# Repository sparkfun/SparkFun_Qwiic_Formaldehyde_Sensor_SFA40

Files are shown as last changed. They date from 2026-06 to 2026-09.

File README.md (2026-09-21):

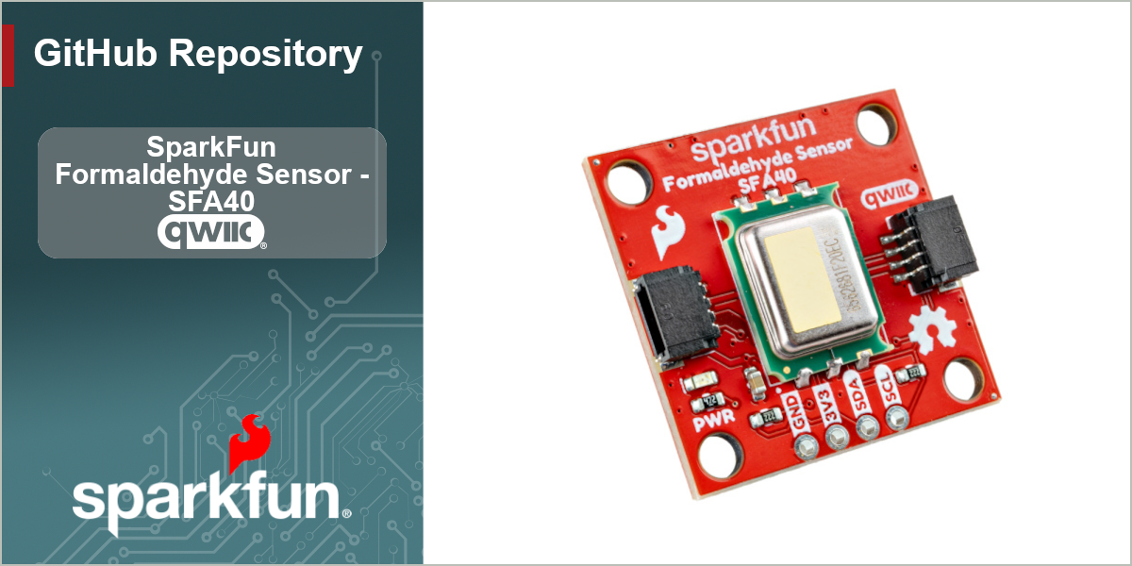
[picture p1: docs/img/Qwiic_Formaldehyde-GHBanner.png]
SparkFun Formaldehyde Sensor - SFA40 (Qwiic) (https://www.sparkfun.com/sparkfun-formaldehyde-sensor-sfa40.html)


The [SparkFun Formaldehyde Sensor - SFA40 (Qwiic)](https://www.sparkfun.com/sparkfun-formaldehyde-sensor-sfa40.html) is a compact indoor air quality breakout built around the SFA40 from Sensirion.
The SFA40 is an electrochemical sensor that measures formaldehyde (HCHO) from 0 to 2000 ppb, with very low cross-sensitivity 
to common indoor gases like ethanol. It is factory-calibrated and outputs concentration directly over I2C, and an onboard 
humidity and temperature sensor compensates the reading automatically. We've wired it to Qwiic connectors so you can read 
calibrated formaldehyde levels with no soldering.

**Note:** The SFA40 needs about 10 minutes after power-on to reach full accuracy, and a status flag in each reading tells you when it is within spec.

## Repository Contents

* **/docs** - Documentation files for GitHub pages
* **/Documents** - Datasheets, additional product information
* **/Hardware** - KiCad design files (.kicad_sch, .kicad_pcb)
* **/Production** - Production panel files

## Documentation

* **[Library](https://github.com/sparkfun/SparkFun_SFA40_Arduino_Library)** - Arduino library for the SparkFun Qwiic Formaldehyde Sensor - SFA40.
* **[Hookup Guide](https://docs.sparkfun.com/SparkFun_Qwiic_Formaldehyde_Sensor_SFA40/)** - Basic hookup guide for the SparkFun Qwiic Formaldehyde Sensor - SFA40.

## Product Versions

* **[SEN-31669](https://www.sparkfun.com/sparkfun-formaldehyde-sensor-sfa40.html)** - Initial release of the SparkFun Qwiic Formaldehyde Sensor - SFA40.

## License Information

This product is _**open source**_!

Please review the LICENSE.md file for license information.

If you have any questions or concerns about licensing, please contact technical support on our [SparkFun forums](https://forum.sparkfun.com/viewforum.php?f=152).

Distributed as-is; no warranty is given.

_- Your friends at SparkFun._

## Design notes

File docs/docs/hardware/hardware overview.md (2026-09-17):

# Hardware Overview

## SFA40 Formaldehyde Sensor

The SFA40 formaldehyde sensor from Sensirion is a compact electrochemical indoor gas sensor designed to measure concentrations of formaldehyde gas. It has very low cross-sensitivity with similar, common indoor gases like ethanol and nitrogen dioxide. It's intended to measure indoor gas concentrations over long periods of time and has a long-term drift of &lt;5ppb (or &lt;5% of the measured value, whichever is larger) per year. The sensor includes humidity and temperature sensing to compensate the formaldehyde signal. Each SFA40 has a unique 48-bit serial number and self-test for verifying the sensor's electrical connections.

The SFA40 provides a calibrated digital output with an accuracy of &plusmn;20ppb (parts per billion) or &plusmn;20% of the total measurement range of 0 to 2000ppb. The sensor does require a 10 minute calibration period on power up. The SFA40 accepts a supply voltage 1.6 to 3.6V (3.3V over Qwiic) and draws an average of 80&micro;A during measurement with a max of 6mA. While idle it draws an average of 60&micro;A. For a complete overview of the SFA40, take a look at the [datasheet](/ref/SFA40.pdf)

## Connectors

### Qwiic Connectors

The board has a pair of Qwiic connectors to make it easy to integrate into a Qwiic circuit. These connect to the SFA40's I<sup>2</sup>C signals along with 3.3V and ground to power the board and communicate with the SFA40.

### Plated Through-Hole (PTH) Header

The board also routes the same signals as the Qwiic connectors (SDA, SCL, 3.3V and Ground) to a 0.1"-spaced plated through-hole header for users who prefer a soldered connection.

## LED

The lone LED on this breakout is a red power status LED.

## Solder Jumpers

The board has two solder jumpers labeled **LED** and **I<sup>2</sup>C**. The **LED** jumper completes the power LED circuit and is CLOSED by default. Open this jumper to disable the power LED. The **I<sup>2</sup>C** jumper is a three-way jumper that pulls the SFA40's SDA and SCL lines to **3.3V** through a pair of **2.2k**&ohm; resistors and is CLOSED by default. Completely open this jumper to disable pullups on the I<sup>2</sup>C bus if necessary.

## Board Dimensions

This breakout matches the Qwiic standard and measures 1" x 1" (22.5mm x 22.5mm) and has four mounting holes that fit a 4-40 screw.

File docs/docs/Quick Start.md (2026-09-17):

# Quick Start Guide

In this Quick Start guide we'll wire the SparkFun Formaldehyde Sensor - SFA40 (Qwiic) into a Qwiic circuit with a RedBoard IoT - RP2350 to get formaldehyde readings from the sensor in just a few short minutes. This guide assumes users have a working knowledge of the Qwiic ecosystem, Arduino IDE and using Arduino libraries. If you're not familiar with those topics or want to learn more about the SFA40, we recommend reading through the other sections of the Hookup Guide.

## Basic Assembly

Since this is a Qwiic breakout, all we need to do is connect it to the RedBoard using a Qwiic cable and then plug the RedBoard into a computer over USB:

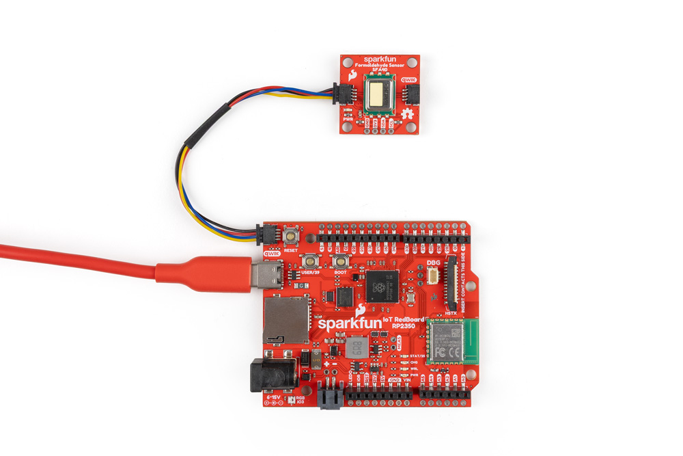
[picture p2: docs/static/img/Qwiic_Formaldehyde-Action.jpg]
Completed Qwiic Assembly


## Arduino Example

With everything wired up, let's use the fourth example in the SFA40 Arduino Library, Sensor Status, to show how the SFA40 performs during initial power up. The SFA40 needs to warm up after power-on. For the first minute the sensor is not ready and the formaldehyde output is forced to 0. Between roughly 1 and 10 minutes the sensor is ready but not yet within specifications. After about 10 minutes the formaldehyde reading is within specifications. This example prints out sensor data along with the sensor status to let you know what state the sensor is in. 

* Open the [Arduino IDE](https://www.arduino.cc/en/software/)
* Install the SparkFun SFA40 Arduino library by searching for "SparkFun SFA40" in the [Libraray Manager tool](https://docs.arduino.cc/software/ide-v2/tutorials/ide-v2-installing-a-library/). Note, this library requires the SparkFun Toolkit to be installed as well. Install that library by searching for "SparkFun Toolkit" in the Library Manager.
* Open "Example04-SensorStatus" from the SFA40 library. Select your Board and Port and click the "Upload" button.
* After the code finishes uploading, open the [serial monitor](https://docs.arduino.cc/software/ide-v2/tutorials/ide-v2-serial-monitor/) with the baud set to **15200**.
* This example initializes the SFA40 on the I<sup>2</sup>C bus and then performs a soft reset to simulate a power cycle. After resetting, the code reads the status report from the SFA40 and prints out "Sensor warming up (not ready)" during the first minute, then prints out "Stabilizing (HCHO ~) ppb, not yet within spec" for the stabilization period. Once the stabilization completes, it prints out stabilized HCHO readings along with temperature and relative humidity.

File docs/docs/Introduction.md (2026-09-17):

---
slug: /
---

# Introduction

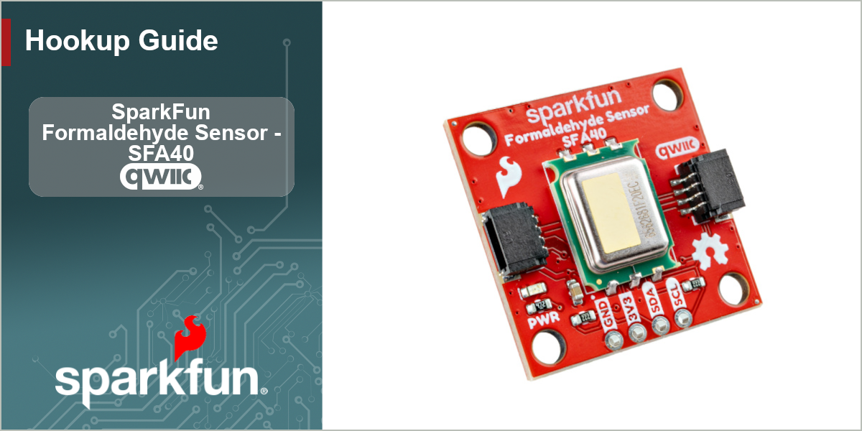
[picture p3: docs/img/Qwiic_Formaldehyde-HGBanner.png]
SparkFun Formaldehyde Sensor - SFA40 (Qwiic) Banner Image


The SparkFun Formaldehyde Sensor - SFA40 (Qwiic) . The SFA40 is a compact electrochemical indoor gas sensor calibrated to measure concentrations of formaldehyde gas with low cross-sensitivity to other common indoor gases like ethanol and nitrogen dioxide. The SFA40 communicates over I<sup>2</sup>C so naturally we've put it on a Qwiic board to easily power and communicate with it in the Qwiic ecosystem. 

In order to follow along with this tutorial you'll need the SparkFun Formaldehyde Sensor - SFA40 (Qwiic) along with the following items:

* [SparkFun RedBoard IoT - RP2350](https://www.sparkfun.com/catalog/product/view/id/17811/s/sparkfun-iot-redboard-rp2350/) (or other Arduino development board)
* [Qwiic Cable](https://www.sparkfun.com/flexible-qwiic-cable-100mm.html)
* [USB-C Cable](https://www.sparkfun.com/usb-c-to-usb-c-cable-1-meter-flexible-silicone.html)

## Topics Covered

This document contains three main sections: **Quick Start Guide**, **Hardware** and **Software**.

The Quick Start Guide goes over assembling the Formaldehyde Sensor in a Qwiic circuit with a compatible Arduino development board and jumps right into installing and uploading an example from the SparkFun SFA40 Arduino Library to get data from the sensor in just a few minutes.

The Hardware pages include a hardware overview that provides a detailed overview of the Formaldehyde Sensor - SFA40 (Qwiic) and all major components on the board. The Hardware Assembly page goes over the steps required to assemble and use the board to measure formaldehyde concentrations with a compatible Arduino development board.

The Software pages give instructions on how to install the SparkFun SFA40 Arduino Library and use some of the examples included in it.

## Resources and Documentation

The **Resources** page has the board design files (KiCad files & schematic), relevant documentation (datasheets, white papers, etc.) and other helpful links. The **Support** page has a troubleshooting section that includes any helpful tips specific to this board as well as information on how to receive technical support from SparkFun.

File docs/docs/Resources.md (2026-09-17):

Check out the following resources for more information about the SparkFun Formaldehyde Sensor - SFA40 (Qwiic).

* [Schematic](/ref/SparkFun_Qwiic_Formaldehyde_Sensor_SFA40.pdf)
* [KiCad Files](/ref/SparkFun_Qwiic_Formaldehyde_Sensor_SFA40.zip)
* [Board Dimensions](/ref/SparkFun_Qwiic_Formaldehyde_Sensor_SFA40.png)
* [Datasheet](/ref/SFA40.pdf) (SFA40)
* [Arduino Library](https://github.com/sparkfun/SparkFun_SFA40_Arduino_Library)
* [GitHub Repository](https://github.com/sparkfun/SparkFun_Qwiic_Formaldehyde_Sensor_SFA40)

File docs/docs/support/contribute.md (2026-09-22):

# Contribute

## Improve our Documentation

All of this documentation can be modified by you! Please help us make it better.

* These pages are contained in the [`docs` folder of the SparkFun Formaldehyde Sensor - SFA40 (Qwiic) repository](https://github.com/sparkfun/SparkFun_Qwiic_Formaldehyde_Sensor_SFA40/tree/main/docs).

### Submit a Correction

1. Fork this repo
2. Add your corrections or improvements to the markdown file
3. File a pull request with your changes, and enjoy making the ~~words~~ ~~worlds~~ world a better place.
    * Once received, the documentation specialist will automatically be notified.
    * We will review your suggested improvements to make sure they are correct and fit within our documentation standards.

## Improve our Hardware Design

This hardware design is open-source! Please help us make it better.

* Our board design files are contained in the [`Hardware` folder of the SparkFun Formaldehyde Sensor - SFA40 (Qwiic) repository](https://github.com/sparkfun/SparkFun_Qwiic_Formaldehyde_Sensor_SFA40/tree/main/Hardware).

### Submit a Design Improvement

1. Fork this repo
2. Add your design improvements
3. File a pull request with your changes, and enjoy making the ~~words~~ ~~worlds~~ world a better place.
    * Once received, the engineer in charge of the original design will automatically be notified.
    * We will review your suggested improvements, if they are within our board design standards and meet our product design requirements, we will flag these changes for our next board revision. *(Please note, that even if your suggestion is accepted, these changes may not be immediate. We may have to cycle through our current product inventory first.)*

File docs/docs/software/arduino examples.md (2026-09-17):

# Arduino Examples

## Example 01 - Basic Readings

The first example demonstrates how to set up the SFA40 and get basic readings from the sensor for formaldehyde (HCHO), relative humidity and temperature. Reminder, the SFA40 requires a 10 minute stabilization period after power up so for the first minute the formaldehyde readings will report as "0". After the first minute, it will output HCHO in ppb but these values are not within the sensor's specification until the sensor has been running for 10 minutes. Example 04 - Status shows how to read the status reports from the SFA40 to get a better idea of when the sensor is ready to report stabilized formaldehyde concentrations.

## Example 02 - Serial Number

The second example shows how to poll the SFA40 for its serial number. Each SFA40 comes with an individual 48-bit serial number that is both etched onto the physical sensor and available for polling using software. This sketch reads it and prints it as a 12-digit hexadecimal value, which matches the serial number laser-marked on the metal cap of the sensor.

## Example 03 - Self Test

The third example demonstrates how to perform a self test on the SFA40 to verify electrical connections and functionality of the sensor. This is mostly used during production but can help diagnose issues with the SFA40 to determine if there is a hardware fault.

## Example 04 - Status

The fourth example shows how to interpret the status variable the SFA40 returns with every measurement. The SFA40 requires about 10 minutes after power up to return valid measurements.

The example simulates a full power-on state by performing a soft reset. For the first minute after this reset, the sensor is "not ready" and reports only 0 formaldehyde concentration. Between one minute and ten minutes, the SFA40 is ready but "not yet within specifications". After ten minutes, the sensor is now within specifications and reports stabilized formaldehyde readings. The main loop then reads the status report from the SFA40 and prints out "Sensor warming up (not ready)" during the first minute, then prints out "Stabilizing (HCHO ~) ppb, not yet within spec" for the stabilization period. After this finishes, it prints out stabilized readings.

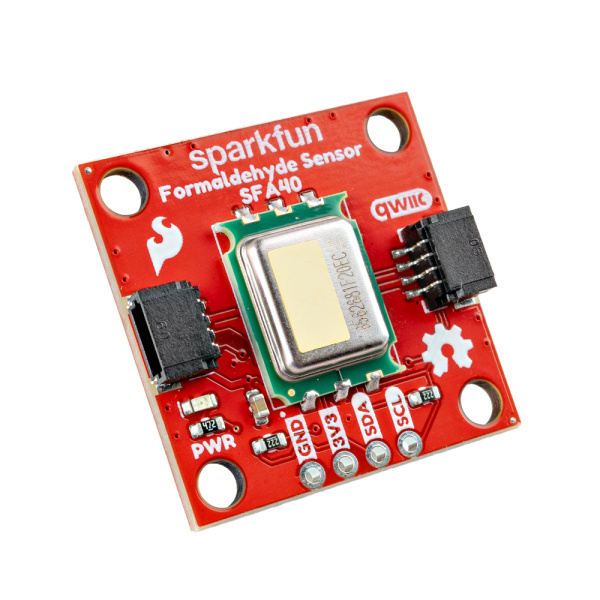
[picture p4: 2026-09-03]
Documents/images/SFA40.png

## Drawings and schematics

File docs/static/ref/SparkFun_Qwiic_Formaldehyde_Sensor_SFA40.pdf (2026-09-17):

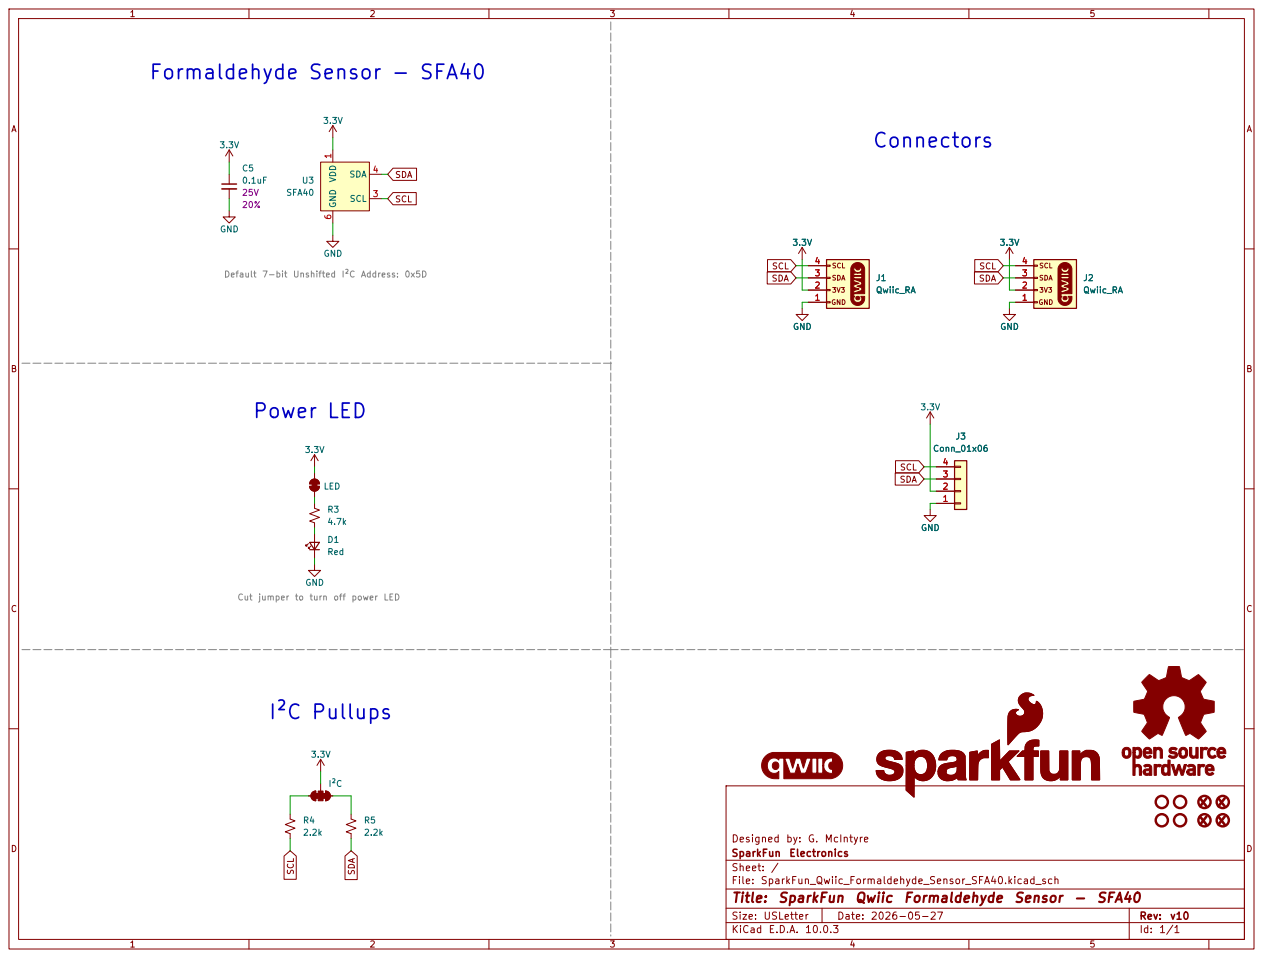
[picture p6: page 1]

3.3V D1Red C5
Default 7-bit Unshifted I²C Address: 0x5D I²C Pullups

Cut jumper to turn off power LED Power LED

Designed by: G. McIntyre
SparkFun Electronics
Sheet: /
File: SparkFun_Qwiic_Formaldehyde_Sensor_SFA40.kicad_sch
Title: SparkFun Qwiic Formaldehyde Sensor - SFA40

Size: USLetter | Rev: v10
KiCad E.D.A. 10.0.3 | Id: 1/1

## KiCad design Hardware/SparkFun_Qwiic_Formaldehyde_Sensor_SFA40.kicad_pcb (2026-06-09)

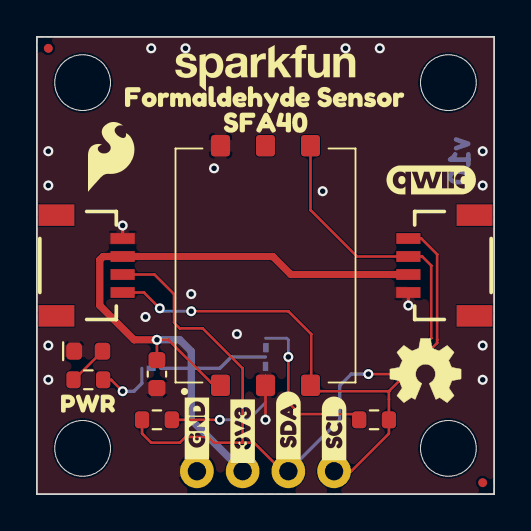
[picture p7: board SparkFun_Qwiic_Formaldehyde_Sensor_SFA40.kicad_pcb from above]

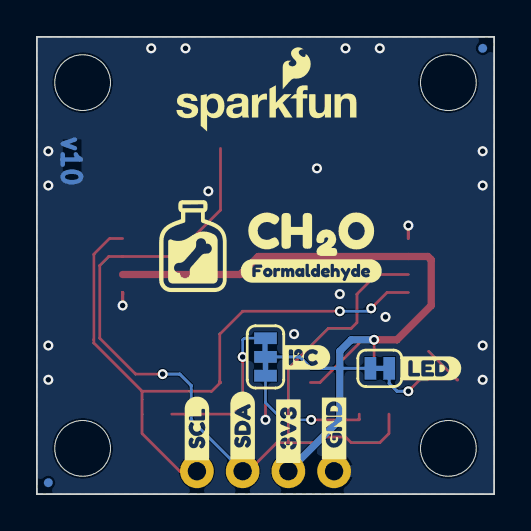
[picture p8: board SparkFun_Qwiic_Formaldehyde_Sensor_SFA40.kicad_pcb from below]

Board: 2 copper layers, 25.4 x 25.4 mm, 37 parts (13 on the bottom side), 8 nets.

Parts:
C5: 0.1uF; C_0603_1608Metric
D1: Red; LED_0603_1608Metric_Red
FID1, FID2, FID3, FID4: Fiducial_0.5mm; Fiducial_0.5mm_Mask1mm
G4: OSHW_Logo; Creative_Commons_License
J1, J2: Qwiic_RA; JST_1x04_P1.0mm_Horizontal_SMD
J3: Conn_01x06; 1x04_P2.54mm
JP1: LED; Jumper_2_NC_Trace
JP2: I²C; Jumper_3_NC-2_Trace
R3: 4.7k; R_0603_1608Metric
R4, R5: 2.2k; R_0603_1608Metric
Ref**: Val**; OSHW_Logo_4mm
ST1, ST2, ST3, ST4: Standoff
U3: SFA40
kibuzzard-6A0365C6: G***; kibuzzard-6A0365C6
kibuzzard-6A23318A: G***; kibuzzard-6A23318A
kibuzzard-6A23378A: G***; kibuzzard-6A23378A
kibuzzard-6A172007: G***; kibuzzard-6A172007
kibuzzard-6A233140: G***; kibuzzard-6A233140
kibuzzard-6A233190: G***; kibuzzard-6A233190
kibuzzard-6A233774: G***; kibuzzard-6A233774
kibuzzard-6A233784: G***; kibuzzard-6A233784
kibuzzard-689A66E2: G***; kibuzzard-689A66E2
kibuzzard-689A66EE: G***; kibuzzard-689A66EE
kibuzzard-689A66F4: G***; kibuzzard-689A66F4
kibuzzard-689A642E: G***; kibuzzard-689A642E
kibuzzard-689A6711: G***; kibuzzard-689A6711
kibuzzard-689A6718: G***; kibuzzard-689A6718
kibuzzard-689A6728: G***; kibuzzard-689A6728
kibuzzard-689A6796: G***; kibuzzard-689A6796

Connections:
3.3V: C5.1, J1.2, J2.2, J3.2, JP1.2 (B), JP2.2 (B), U3.1 (VDD)
GND: C5.2, D1.1 (K), J1.1, J2.1, J3.1, U3.2 (GND), U3.6 (GND)
unnamed: D1.2 (A), R3.1
unnamed: JP1.1 (A), R3.2
unnamed: JP2.1 (A), R5.2
unnamed: JP2.3 (C), R4.2
SCL: J1.4, J2.4, J3.4, R4.1, U3.3 (SCL)
SDA: J1.3, J2.3, J3.3, R5.1, U3.4 (SDA)

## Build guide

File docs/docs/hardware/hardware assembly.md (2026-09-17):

# Hardware Assembly

Let's go ahead and wire this up in a Qwiic circuit to start using the SFA40.

## Qwiic Assembly

Since thi is a Qwiic breakout, all we need to do is plug it into a Qwiic-comaptible development board, like the RedBoard IoT shown below, with a Qwiic cable. After that, plug the RedBoard into a computer over USB-C and we can move on to using the SparkFun SFA40 Arduino library to get data from the sensor:

Completed Qwiic Assembly

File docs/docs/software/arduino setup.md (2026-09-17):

# Arduino Setup

This example assumes you are using the latest version of the Arduino IDE on your desktop. If this is your first time using Arduino IDE, library, or board add-on, please review the following tutorials.

- [Installing the Arduino IDE](https://learn.sparkfun.com/tutorials/installing-arduino-ide)
- [Installing an Arduino Library](https://learn.sparkfun.com/tutorials/installing-an-arduino-library)
- [Installing Board Definitions in the Arduino IDE](https://learn.sparkfun.com/tutorials/installing-board-definitions-in-the-arduino-ide)

## Installing the SparkFun SFA40 Arduino Library

This library is built using the [SparkFun Toolkit](https://github.com/sparkfun/SparkFun_Toolkit) so you'll need to make sure that is installed before using this library. Install the SparkFun Toolkit with the Arduino Library manager by searching "SparkFun Toolkit" and installing the latest version. Users who prefer manually installing Arduino Libraries can download it from the [GitHub Repository](https://github.com/sparkfun/SparkFun_Toolkit).

## Library Setup

The SparkFun SFA40 Arduino Library includes four examples that go through the main features of the SFA40 and demonstrate how to get data from the sensor. Install the library using the Arduino Library Manager tool by searching for "SparkFun SFA40" and install the latest version. If you'd prefer to manually install the library, you can download it from the [GitHub Repository](https://github.com/sparkfun/SparkFun_SFA40_Arduino_Library) or you can download a ZIP of the repository [here](https://github.com/sparkfun/SparkFun_SFA40_Arduino_Library/archive/refs/heads/main.zip).

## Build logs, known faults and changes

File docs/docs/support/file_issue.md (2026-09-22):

# Submit Issues

## Support

If you need technical assistance and more information on a product that is not working as you expected, visit the [SparkFun Community](https://community.sparkfun.com). The community forums are monitored by the SparkFun Technical Support Team and the SparkFun community as a whole.

## Existing Issue

Spot something wrong? Please check the list of reported and fixed issues  .  in this repository.

## Discrepancies in the Documentation

All of this documentation can be modified by you! Please help us make it better.

* The documentation files for these pages are contained in the [`docs` folder of the SparkFun Formaldehyde Sensor - SFA40 (Qwiic) repository](https://github.com/sparkfun/SparkFun_Qwiic_Formaldehyde_Sensor_SFA40/tree/main/docs).

### Spot something wrong?

If a section of the documentation is incorrect, please [open an issue](https://github.com/sparkfun/SparkFun_Qwiic_Formaldehyde_Sensor_SFA40/issues) and let us know.

### Do you have a suggested correction?

1. With a GitHub account, fork this repo
2. Add your correction(s) or improvement(s) to the markdown file(s)
3. File a pull request with your changes, and enjoy making the ~~words~~ ~~worlds~~ world a better place.
    * Once received, the documentation specialist will automatically be notified.
    * We will review your suggested improvement(s) to make sure they are correct and fit within our documentation standards.

## Problems in the Hardware Design

All of our designs are open-source! Please help us make it better.

* Our board design files are contained in the [`Hardware` folder of the SparkFun Formaldehyde Sensor - SFA40 (Qwiic) repository](https://github.com/sparkfun/SparkFun_Qwiic_Formaldehyde_Sensor_SFA40/tree/main/Hardware).

### Does something not make sense?

If part of the design is confusing, please [open an issue](https://github.com/sparkfun/SparkFun_Qwiic_Formaldehyde_Sensor_SFA40/issues) and let us know.

### Did we forget to include an important function of the board?

Please keep in mind that we may intentionally exclude certain functions of the board to meet our product design requirements.

If part of the board's functionality is missing, please [open an issue](https://github.com/sparkfun/SparkFun_Qwiic_Formaldehyde_Sensor_SFA40/issues) and file a feature request.

### Do you wish to contribute directly to improving the board design?

1. With a GitHub account, Fork this repo
2. Add your design improvement(s)
3. File a pull request with your changes, and enjoy making the ~~words~~ ~~worlds~~ world a better place.
    * Once received, the engineer in charge of the original design will automatically be notified.
    * We will review your suggested improvement(s), if they are within our board design standards and meet our product design requirements, we will flag these changes for our next board revision. *(Please note, that even if your suggestion is accepted, these changes may not be immediate. We may have to cycle through our current product inventory first.)*

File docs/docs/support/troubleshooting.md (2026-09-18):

# Troubleshooting

## Stabilization Period

The SFA40 requires a stabilization of approximately 10 minutes before it returns formaldehyde readings that are within the sensor's specifications. During the first minute after power-up or reset it returns formaldehyde readings of 0. After the first minute, the sensor returns formaldehyde readings but they are not considered within specification by the sensor. The SFA40 reports a status indicator byte to allow users to determine what state the sensor is in. Example 4 in the SparkFun SFA40 Arduino Library demonstrates how to poll the SFA40 for the status byte to determine the validity of formaldehyde data.

## Support

If you need technical assistance or more information on a product that is not working as you expected, we recommend heading on over to the [SparkFun Technical Assistance](https://www.sparkfun.com/technical_assistance) page for some initial troubleshooting.

If you need technical assistance and more information on a product that is not working as you expected, visit the [SparkFun Community](https://community.sparkfun.com). The community forums are monitored by the SparkFun Technical Support Team and the SparkFun community as a whole. If this is your first visit to our forum, you'll need to create a [Forum Account](https://forum.sparkfun.com/ucp.php?mode=register) to post questions.

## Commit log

2026-06-09 Design Review Changes
    [SparkFun_Qwiic_Formaldehyde_Sensor_SFA40.kicad_pcb, SparkFun_Qwiic_Formaldehyde_Sensor_SFA40.kicad_sch]
2026-06-09 Rolls version to v10
    [SparkFun_Qwiic_Formaldehyde_Sensor_SFA40.kicad_pcb, SparkFun_Qwiic_Formaldehyde_Sensor_SFA40.kicad_sch]

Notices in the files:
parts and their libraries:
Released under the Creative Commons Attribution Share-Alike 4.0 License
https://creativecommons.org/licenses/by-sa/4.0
